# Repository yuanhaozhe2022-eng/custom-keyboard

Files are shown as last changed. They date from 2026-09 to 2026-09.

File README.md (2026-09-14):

# custom-keyboard

Hi, my name is Eric and this is my submission on the Hack Club KEEB project.

Short description:
It's a split, 65%-style mechanical keyboard with an integrated plate, split spacebar, rotary encoder, and a small OLED display. Firmware runs on RMK.

Specs:
- MCU: Raspberry Pi Pico (RP2040)
- Matrix: 5 rows x 13~14 columns, wired matrix
- Layout: split 65% in one case, both halves wired directly to a single Pico (no wireless link for now)
- Extras: rotary encoder (volume control), 0.91" OLED (I2C)
- Case: integrated plate, 3D printed in PETG (~230g), reserved space for future add-ons
- Firmware: RMK, built via GitHub Actions cloud compilation

Rendered Pictures:





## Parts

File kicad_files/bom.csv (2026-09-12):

Reference | Qty | Value | DNP | Exclude from BOM | Exclude from Board | Exclude from Simulation | Exclude from Position Files | Footprint | Datasheet
A1 | 1 | RaspberryPi_Pico |  |  |  |  | ${EXCLUDE_FROM_POS_FILES} | Module:RaspberryPi_Pico_Common_THT | https://datasheets.raspberrypi.com/pico/pico-datasheet.pdf
D1,D2,D3,D4,D5,D6,D7,D8,D9,D10,D11,D12,D13,D14,D15,D16,D17,D18,D19,D20,D21,D22,D23,D24,D25,D26,D27,D28,D29,D30,D31,D32,D33,D34,D35,D36,D37,D38,D39,D40,D41,D42,D43,D44,D45,D46,D47,D48,D49,D50,D51,D52,D53,D54,D55,D56,D57,D58,D59,D60,D61,D62,D63,D64,D65,D68 | 66 | 1N4148 |  |  |  |  | ${EXCLUDE_FROM_POS_FILES} | Diode_THT:D_DO-35_SOD27_P7.62mm_Horizontal | https://assets.nexperia.com/documents/data-sheet/1N4148_1N4448.pdf
J1,J2,J3,J4,J5,J6,J7,J8,J9,J10,J11,J12,J13,J14,J15,J16,J17,J18,J19,J20,J21,J22,J23,J24,J25,J26,J27,J28,J29,J30,J31,J32,J33,J34,J35,J36,J37,J38,J39,J40 | 40 | Conn_01x01 |  |  |  |  | ${EXCLUDE_FROM_POS_FILES} | Connector_Wire:SolderWire-1sqmm_1x01_D1.4mm_OD2.7mm
S1,S2,S3,S4,S5 | 5 | MX_stab |  |  |  |  | ${EXCLUDE_FROM_POS_FILES} | PCM_marbastlib-mx:STAB_MX_2u
SW1,SW2,SW3,SW4,SW5,SW6,SW7,SW8,SW9,SW10,SW11,SW12,SW13,SW14,SW15,SW16,SW17,SW18,SW19,SW20,SW21,SW22,SW23,SW24,SW25,SW26,SW27,SW28,SW29,SW30,SW31,SW32,SW33,SW34,SW35,SW36,SW37,SW38,SW39,SW40,SW41,SW42,SW43,SW44,SW45,SW46,SW47,SW48,SW49,SW50,SW51,SW52,SW53,SW54,SW55,SW56,SW57,SW58,SW59,SW60,SW61,SW62,SW63,SW64,SW65,SW68 | 66 | SW_Push |  |  |  |  | ${EXCLUDE_FROM_POS_FILES} | PCM_marbastlib-mx:SW_MX_1u
SW66 | 1 | RotaryEncoder_Switch |  |  |  |  | ${EXCLUDE_FROM_POS_FILES} | Rotary_Encoder:RotaryEncoder_Alps_EC11E-Switch_Vertical_H20mm
U1 | 1 | ER_OLEDM0.91_1x-I2C |  |  |  |  | ${EXCLUDE_FROM_POS_FILES} | Display:ER_OLEDM0.91_1x-I2C | https://www.buydisplay.com/download/manual/ER-OLEDM0.91-1_Datasheet.pdf

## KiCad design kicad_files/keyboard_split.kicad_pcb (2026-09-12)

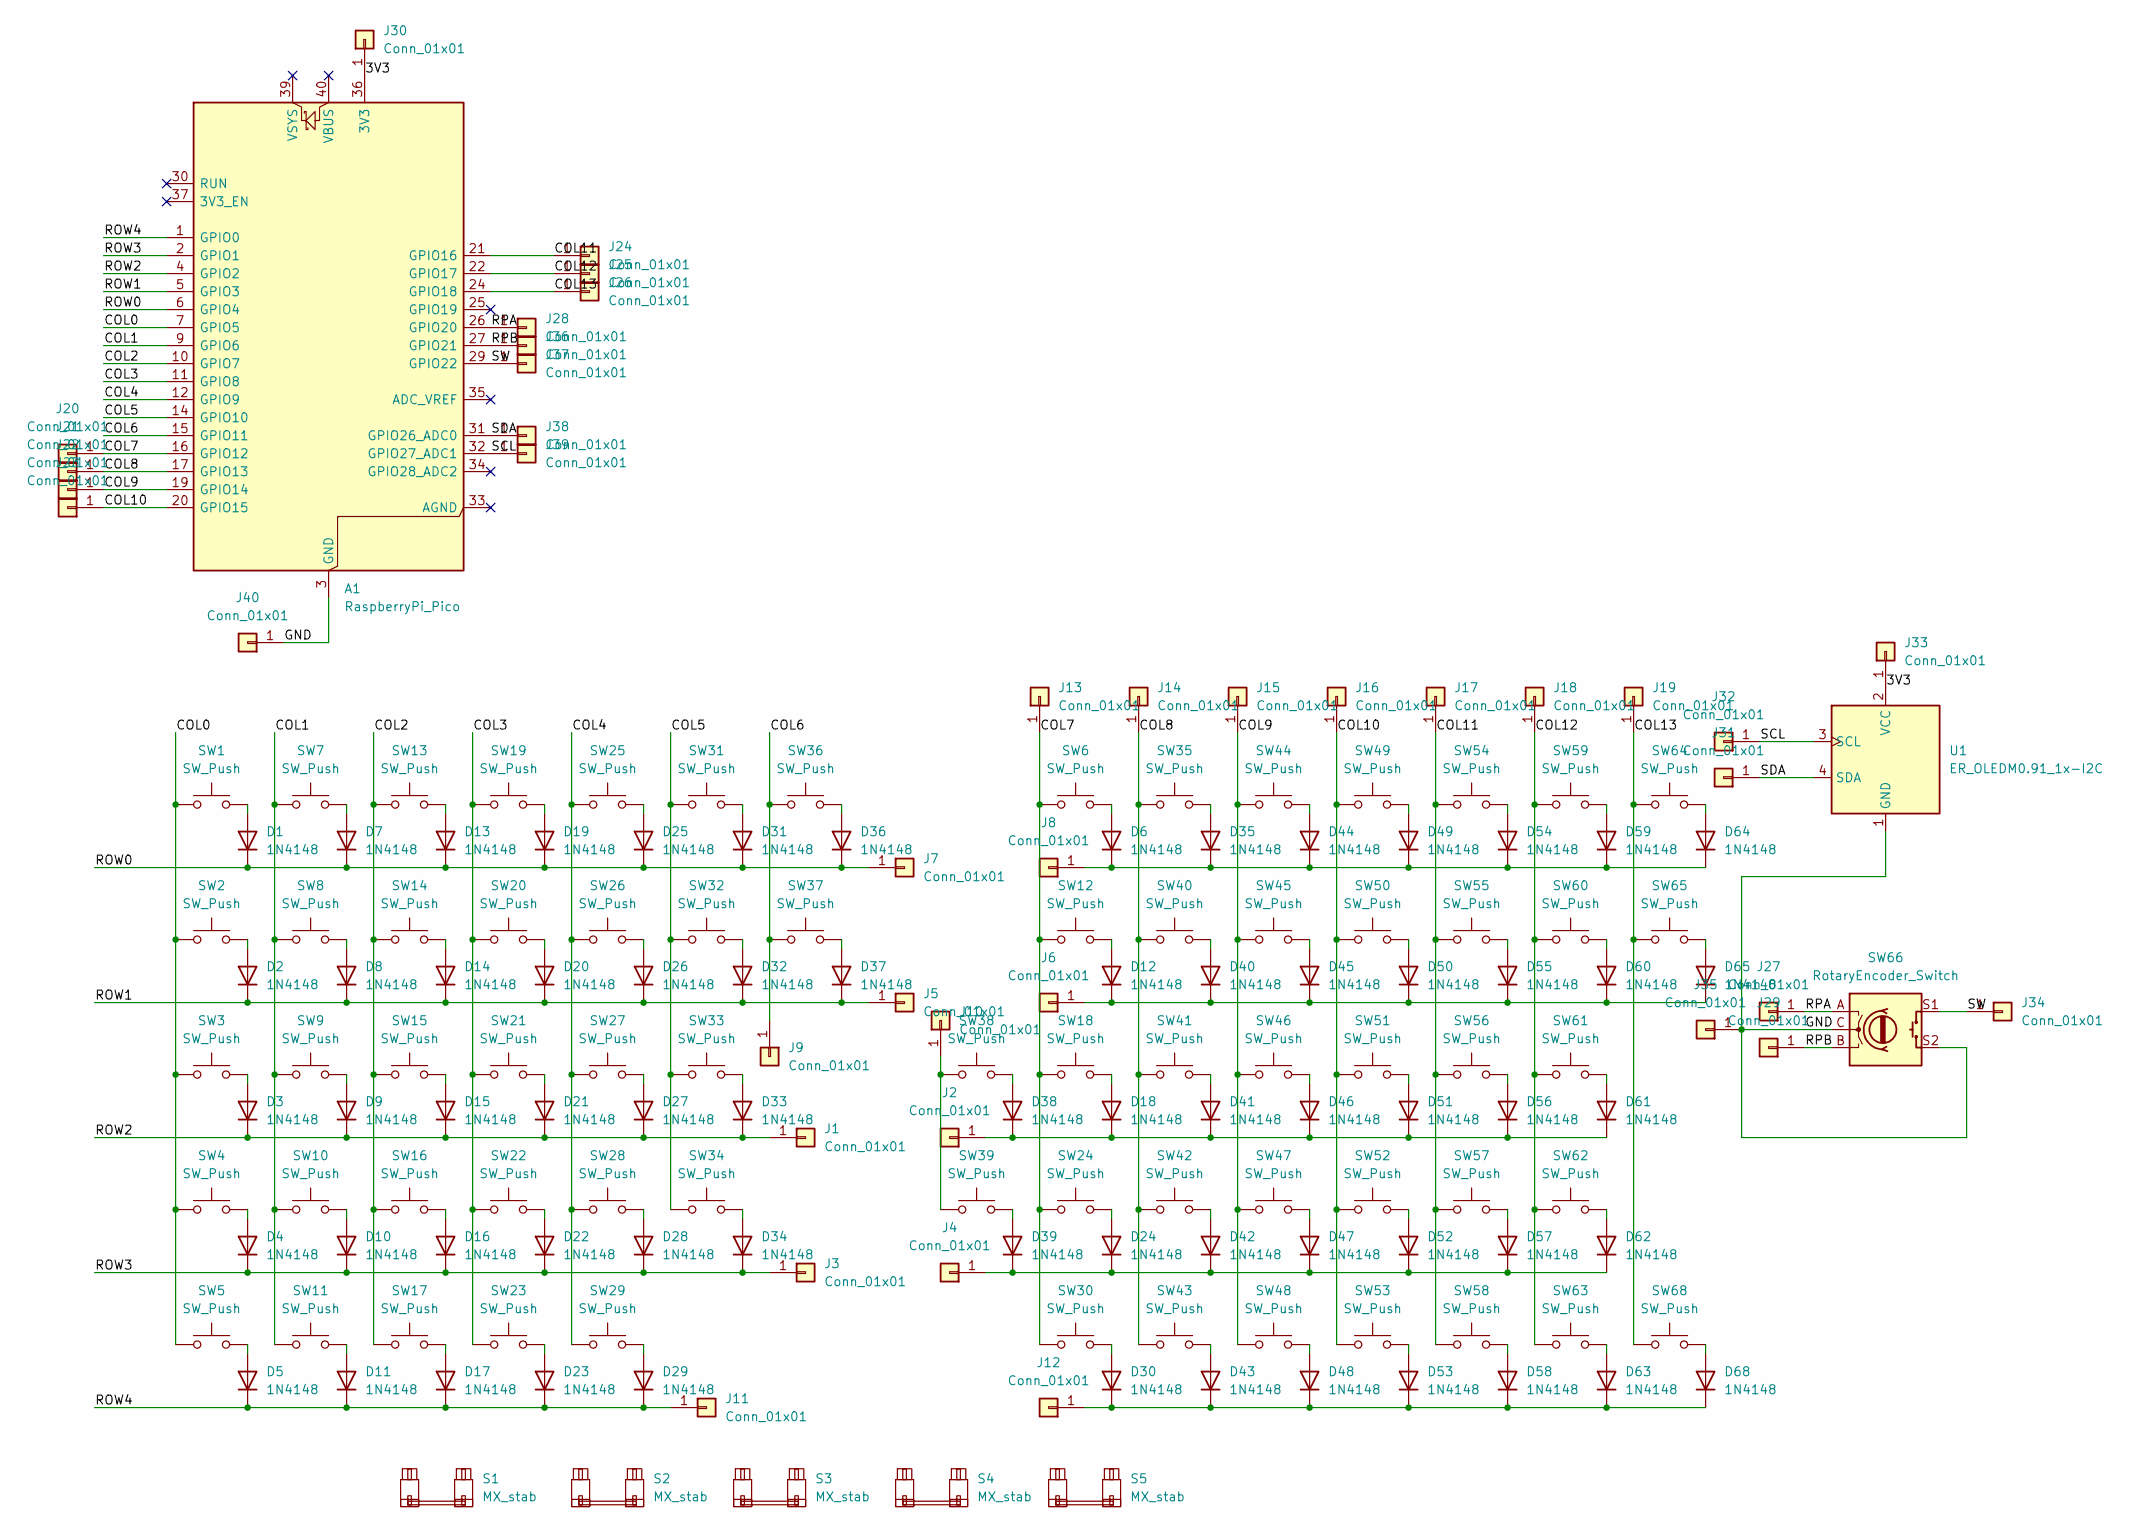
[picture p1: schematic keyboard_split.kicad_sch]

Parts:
A1: RaspberryPi_Pico; RaspberryPi_Pico_Common_THT
D1, D2, D3, D4, D5, D6, D7, D8, D9, D10, D11, D12, D13, D14, D15, D16, D17, D18, D19, D20, D21, D22, D23, D24, D25, D26, D27, D28, D29, D30, D31, D32, D33, D34, D35, D36, D37, D38, D39, D40, D41, D42, D43, D44, D45, D46, D47, D48, D49, D50, D51, D52, D53, D54, D55, D56, D57, D58, D59, D60, D61, D62, D63, D64, D65, D68: 1N4148; D_DO-35_SOD27_P7.62mm_Horizontal
J1, J2, J3, J4, J5, J6, J7, J8, J9, J10, J11, J12, J13, J14, J15, J16, J17, J18, J19, J20, J21, J22, J23, J24, J25, J26, J27, J28, J29, J30, J31, J32, J33, J34, J35, J36, J37, J38, J39, J40: Conn_01x01; SolderWire-1sqmm_1x01_D1.4mm_OD2.7mm
S1, S2, S3, S4, S5: MX_stab; STAB_MX_2u
SW1, SW2, SW3, SW4, SW5, SW6, SW7, SW8, SW9, SW10, SW11, SW12, SW13, SW14, SW15, SW16, SW17, SW18, SW19, SW20, SW21, SW22, SW23, SW24, SW25, SW26, SW27, SW28, SW29, SW30, SW31, SW32, SW33, SW34, SW35, SW36, SW37, SW38, SW39, SW40, SW41, SW42, SW43, SW44, SW45, SW46, SW47, SW48, SW49, SW50, SW51, SW52, SW53, SW54, SW55, SW56, SW57, SW58, SW59, SW60, SW61, SW62, SW63, SW64, SW65, SW68: SW_Push; SW_MX_1u
SW66: RotaryEncoder_Switch; RotaryEncoder_Alps_EC11E-Switch_Vertical_H20mm
U1: ER_OLEDM0.91_1x-I2C

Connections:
/COL0: A1.7 (GPIO5), SW1.1, SW2.1, SW3.1, SW4.1, SW5.1
/COL1: A1.9 (GPIO6), SW7.1, SW8.1, SW9.1, SW10.1, SW11.1
/COL2: A1.10 (GPIO7), SW13.1, SW14.1, SW15.1, SW16.1, SW17.1
/COL3: A1.11 (GPIO8), SW19.1, SW20.1, SW21.1, SW22.1, SW23.1
/COL4: A1.12 (GPIO9), SW25.1, SW26.1, SW27.1, SW28.1, SW29.1
/COL5: A1.14 (GPIO10), SW31.1, SW32.1, SW33.1, SW34.1
/COL6: A1.15 (GPIO11), J9.1 (Pin_1_1), SW36.1, SW37.1
/COL7: A1.16 (GPIO12), J13.1 (Pin_1_1), J20.1 (Pin_1_1), SW6.1, SW12.1, SW18.1, SW24.1, SW30.1
/COL8: A1.17 (GPIO13), J14.1 (Pin_1_1), J21.1 (Pin_1_1), SW35.1, SW40.1, SW41.1, SW42.1, SW43.1
/COL9: A1.19 (GPIO14), J15.1 (Pin_1_1), J22.1 (Pin_1_1), SW44.1, SW45.1, SW46.1, SW47.1, SW48.1
/COL10: A1.20 (GPIO15), J16.1 (Pin_1_1), J23.1 (Pin_1_1), SW49.1, SW50.1, SW51.1, SW52.1, SW53.1
/COL11: A1.21 (GPIO16), J17.1 (Pin_1_1), J24.1 (Pin_1_1), SW54.1, SW55.1, SW56.1, SW57.1, SW58.1
/COL12: A1.22 (GPIO17), J18.1 (Pin_1_1), J25.1 (Pin_1_1), SW59.1, SW60.1, SW61.1, SW62.1, SW63.1
/COL13: A1.24 (GPIO18), J19.1 (Pin_1_1), J26.1 (Pin_1_1), SW64.1, SW65.1, SW68.1
/ROW0: A1.6 (GPIO4), D1.1 (K), D7.1 (K), D13.1 (K), D19.1 (K), D25.1 (K), D31.1 (K), D36.1 (K), J7.1 (Pin_1_1)
/ROW1: A1.5 (GPIO3), D2.1 (K), D8.1 (K), D14.1 (K), D20.1 (K), D26.1 (K), D32.1 (K), D37.1 (K), J5.1 (Pin_1_1)
/ROW2: A1.4 (GPIO2), D3.1 (K), D9.1 (K), D15.1 (K), D21.1 (K), D27.1 (K), D33.1 (K), J1.1 (Pin_1_1)
/ROW3: A1.2 (GPIO1), D4.1 (K), D10.1 (K), D16.1 (K), D22.1 (K), D28.1 (K), D34.1 (K), J3.1 (Pin_1_1)
/ROW4: A1.1 (GPIO0), D5.1 (K), D11.1 (K), D17.1 (K), D23.1 (K), D29.1 (K), J11.1 (Pin_1_1)
/RPA: A1.26 (GPIO20), J27.1 (Pin_1_1), J28.1 (Pin_1_1), SW66.A
/RPB: A1.27 (GPIO21), J29.1 (Pin_1_1), J36.1 (Pin_1_1), SW66.B
/SCL: A1.32 (GPIO27_ADC1), J32.1 (Pin_1_1), J39.1 (Pin_1_1), U1.3 (SCL)
/SDA: A1.31 (GPIO26_ADC0), J31.1 (Pin_1_1), J38.1 (Pin_1_1), U1.4 (SDA)
/SW: A1.29 (GPIO22), J34.1 (Pin_1_1), J37.1 (Pin_1_1), SW66.S1
unnamed: D1.2 (A), SW1.2
unnamed: D2.2 (A), SW2.2
unnamed: D3.2 (A), SW3.2
unnamed: D4.2 (A), SW4.2
unnamed: D5.2 (A), SW5.2
unnamed: D6.2 (A), SW6.2
unnamed: D7.2 (A), SW7.2
unnamed: D8.2 (A), SW8.2
unnamed: D9.2 (A), SW9.2
unnamed: D10.2 (A), SW10.2
unnamed: D11.2 (A), SW11.2
unnamed: D12.2 (A), SW12.2
unnamed: D12.1 (K), D40.1 (K), D45.1 (K), D50.1 (K), D55.1 (K), D60.1 (K), D65.1 (K), J6.1 (Pin_1_1)
unnamed: D13.2 (A), SW13.2
unnamed: D14.2 (A), SW14.2
unnamed: D15.2 (A), SW15.2
unnamed: D16.2 (A), SW16.2
unnamed: D17.2 (A), SW17.2
unnamed: D18.2 (A), SW18.2
unnamed: D18.1 (K), D38.1 (K), D41.1 (K), D46.1 (K), D51.1 (K), D56.1 (K), D61.1 (K), J2.1 (Pin_1_1)
unnamed: D19.2 (A), SW19.2
unnamed: D20.2 (A), SW20.2
unnamed: D21.2 (A), SW21.2
unnamed: D22.2 (A), SW22.2
unnamed: D23.2 (A), SW23.2
unnamed: D24.2 (A), SW24.2
unnamed: D24.1 (K), D39.1 (K), D42.1 (K), D47.1 (K), D52.1 (K), D57.1 (K), D62.1 (K), J4.1 (Pin_1_1)
unnamed: D25.2 (A), SW25.2
unnamed: D26.2 (A), SW26.2
unnamed: D27.2 (A), SW27.2
unnamed: D28.2 (A), SW28.2
unnamed: D29.2 (A), SW29.2
unnamed: D30.2 (A), SW30.2
unnamed: D30.1 (K), D43.1 (K), D48.1 (K), D53.1 (K), D58.1 (K), D63.1 (K), D68.1 (K), J12.1 (Pin_1_1)
unnamed: D31.2 (A), SW31.2
unnamed: D32.2 (A), SW32.2
unnamed: D33.2 (A), SW33.2
unnamed: D34.2 (A), SW34.2
unnamed: D35.2 (A), SW35.2
unnamed: D6.1 (K), D35.1 (K), D44.1 (K), D49.1 (K), D54.1 (K), D59.1 (K), D64.1 (K), J8.1 (Pin_1_1)
unnamed: D36.2 (A), SW36.2
unnamed: D37.2 (A), SW37.2
unnamed: D38.2 (A), SW38.2
unnamed: D39.2 (A), SW39.2
unnamed: D40.2 (A), SW40.2
unnamed: D41.2 (A), SW41.2
unnamed: D42.2 (A), SW42.2
unnamed: D43.2 (A), SW43.2
unnamed: D44.2 (A), SW44.2
unnamed: D45.2 (A), SW45.2
unnamed: D46.2 (A), SW46.2
unnamed: D47.2 (A), SW47.2
unnamed: D48.2 (A), SW48.2
unnamed: D49.2 (A), SW49.2
unnamed: D50.2 (A), SW50.2
unnamed: D51.2 (A), SW51.2
unnamed: D52.2 (A), SW52.2
unnamed: D53.2 (A), SW53.2
unnamed: D54.2 (A), SW54.2
unnamed: D55.2 (A), SW55.2
unnamed: D56.2 (A), SW56.2
unnamed: D57.2 (A), SW57.2
unnamed: D58.2 (A), SW58.2
unnamed: D59.2 (A), SW59.2
unnamed: D60.2 (A), SW60.2
unnamed: D61.2 (A), SW61.2
unnamed: D62.2 (A), SW62.2
unnamed: D63.2 (A), SW63.2
unnamed: D64.2 (A), SW64.2
unnamed: D65.2 (A), SW65.2
unnamed: D68.2 (A), SW68.2
unnamed: J10.1 (Pin_1_1), SW38.1, SW39.1

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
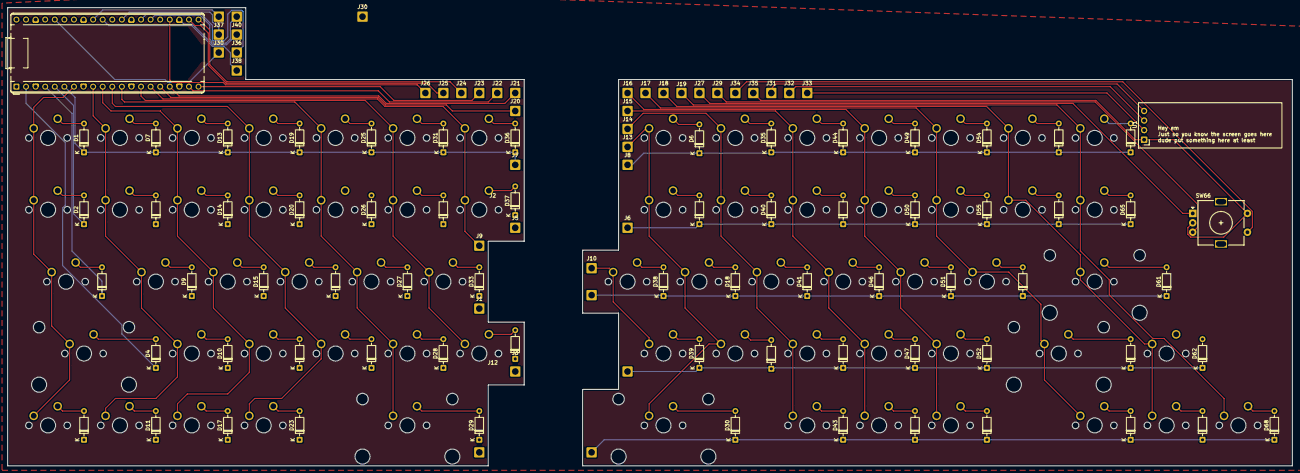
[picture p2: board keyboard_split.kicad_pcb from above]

Board: 2 copper layers, 340.5 x 121.4 mm, 181 parts (0 on the bottom side), 98 nets.

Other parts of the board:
J30#2: Conn_01x01; SolderWire-1sqmm_1x01_D1.4mm_OD2.7mm
S6, S7: MX_stab; STAB_MX_2u

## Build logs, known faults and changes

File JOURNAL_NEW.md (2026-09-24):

A month away from the deadline, also my first time making one of these PCBs.
I’m thinking about a split-in-the-middle 65% keyboard with integrated plate design

Written Clear goal:
- Make it work, of course
- Standard 65% Keyboard
- A split in the middle so it can fold for portability
- Future wireless upgrade
- Function keys by pressing down on a designated fn key
- Leaving space for additional features in the future

Rough idea sketch, took me like an hour, this is not going to go well =(


**TIME SPENT: 1h**
Finished the Schematics in roughly 5 hours, really took longer than I expected, I had to go into the library and add 3D models manually which is a pain. Also have to check for connection errors individually. Added some extra features including an encoder and an OLED screen because why not? They are quite useful sometimes.


**TIME SPENT: 5h**

Laying out the PCB right now, I spent a long time getting the spacing part figured out since I have never used KiCAD before. I didnt even know you’d have to drag from the exact same place (The center, usually) to make everything aligned. Though I do have experience with other older school project software like Traxmaker, It’s like apple to bananas, therefore I took a while to get everything all looking nice and well placed even following the guide



Finished PCB that took me 4 hours of grinding, Might look odd but everything should work. Got like 48 different DRC errors but after checking each one of them they are all false in my case.

Cool 3D render I would REALLY like to show, raytraced with my 5060 (Why is there a raytracing button there anyway?)


**TIME SPENT: 4h**

Exported the 3D model of the entire PCB and ready for case design now.

Case design is done now, took me roughly 2 hours, integrated plate so it’s easy to assemble, used the top empty space as sort of a reserve for future new features if i were ever going to add something new.


**TIME SPENT: 2h**

Fun fact: the encoder knob is the result of an intersection boolean of a cylinder with a gear.



The top empty space is left empty for future add-ons. For example, Since I love driving in Assetto Corsa but I travel frequently and can't bring a whole racing setup with me, it could be used to install a whole LED bulb bar recreating the rev speed LED panel of a race car, That will be really handy for sim racing.

Screen well integrated into the keyboard chassis with some fillet and chamfer.



Put it in my slicer and sliced for my Elegoo CC (not Claude Code, it means Centauri Carbon), uses roughly 230 grams of PETG filament by estimation.
And with that, I’m gonna start with the firmware =)



Hours Passed, I’m still mapping out the keyboard in the .toml, this is genuinely a pain, but one good thing is I do get to map the encoder in RMK which makes everything more convenient.



For now, I will pass on the OLED screen since I do want to get everything shipped and test the keyboard itself out first.

Yay me happy hehehehhe build.yml yeye green checkmarkeiorhaoiwh me happy


**TIME SPENT: 3h**

Really took me a long time to map each individual keys and verifying them later just to find out i messed up somewhere and took another few hours to figure it out.

And with that on the clock, I spent around **15 hours** in total, the PCB part is extremely time consuming though it isn't complex.

BOM included in the repository.

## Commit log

2026-09-12 PCB manufacturing stuff
    [bom.csv]
2026-09-12 KiCAD files
    [keyboard_split.kicad_pcb, keyboard_split.kicad_sch]
2026-09-12 Move KiCAD files into kicad_files folder
    [bom.csv, keyboard_split.kicad_pcb, keyboard_split.kicad_sch]
2026-09-13 Update JOURNAL_NEW.md with PCB design progress
    Documented the progress and challenges faced while designing a custom 65% split keyboard PCB, including schematic completion, layout adjustments, and firmware mapping.
2026-10-16 New BOM with price
2026-10-26 Move BOM files to repo root
2026-10-26 Update README with note about bom.csv movement
    Added a humorous note about using Claude to move the bom.csv file.
2026-10-26 Move STEP file and Gerbers into folders
2026-10-26 Update JOURNAL.md with project progress details
    Documented time spent and additional features added to the schematics.
2026-10-26 Enhance keyboard description in README
    Updated the description to include 'custom PCB' in the keyboard features.
2026-10-26 Replace bom.csv with cleaned BOM
2026-10-26 Added entire assembly as STEP via LFS, moved firmware out of zip.
2026-10-27 Added necessary info in bom.csv
2026-10-27 fixed CAD issues
2026-10-27 Properly formatted bom.csv
2026-10-29 Added PCB Price
2026-10-29 Fixed PCB error
